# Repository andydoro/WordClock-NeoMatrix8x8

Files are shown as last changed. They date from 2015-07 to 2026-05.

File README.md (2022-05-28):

 WORD CLOCK - NeoMatrix 8x8 Desktop Edition
================
 by [Andy Doro](https://andydoro.com/) & [Dano Wall](https://github.com/danowall)
 
https://andydoro.com/wordclockdesktop/

[Adafruit Learn Guide](https://learn.adafruit.com/neomatrix-8x8-word-clock/)

A word clock which uses NeoPixel RGB LEDs for a color shifting effect.

Hardware
-------
 
 - [Trinket Pro 5V](https://www.adafruit.com/product/2000) (should work with other Arduino-compatibles with minor modifications) 
 - [DS1307 RTC breakout](https://www.adafruit.com/products/3296)
 - [NeoPixel NeoMatrix 8x8](https://www.adafruit.com/products/1487)
 - laser cut faceplate & enclosure
 
Software
-------
 
This code requires the following libraries:
 
 - [RTClib](https://github.com/adafruit/RTClib)
 - [DST_RTC](https://github.com/andydoro/DST_RTC)
 - [Adafruit_GFX](https://github.com/adafruit/Adafruit-GFX-Library)
 - [Adafruit_NeoPixel](https://github.com/adafruit/Adafruit_NeoPixel)
 - [Adafruit_NeoMatrix](https://github.com/adafruit/Adafruit_NeoMatrix)

Wiring
-------

 - Solder DS1307 breakout to Trinket Pro, A2 to GND, A3 to PWR, A4 to SDA, A5 to SCL  
   If you leave off / clip the unused SQW pin on the RTC breakout, the breakout can sit right on top of the Trinket Pro for a compact design! It'll be difficult to reach the Trinket Pro reset button, but you can activate the bootloader by plugging in the USB.
 - Solder NeoMatrix 5V to Trinket 5V, GND to GND, DIN to Trinket Pro pin 8.

grid pattern
-------

 ```
 A T W E N T Y D
 Q U A R T E R Y
 F I V E H A L F
 D P A S T O R O
 F I V E I G H T
 S I X T H R E E
 T W E L E V E N
 F O U R N I N E
 ```
 
Acknowledgements:
  - Thanks [Dano](https://github.com/danowall) for faceplate / 3D models & project inspiration!

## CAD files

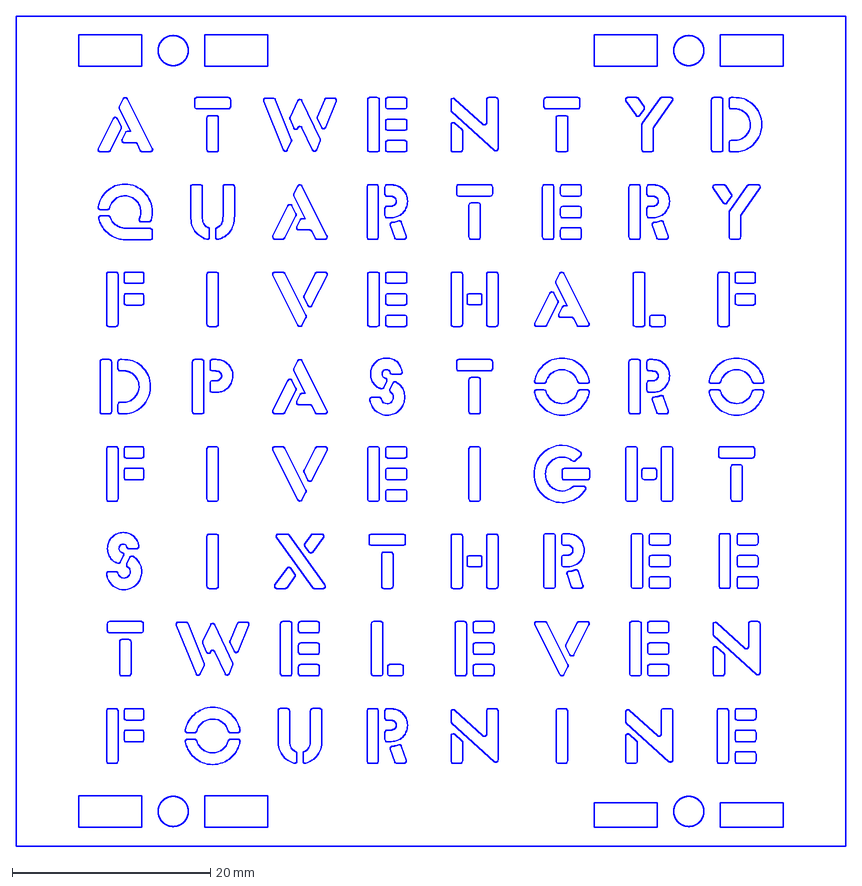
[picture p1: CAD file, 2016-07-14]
laser_cut_enclosure/wordclock_faceplate_ponoko.dxf
83.8 x 83.8 mm

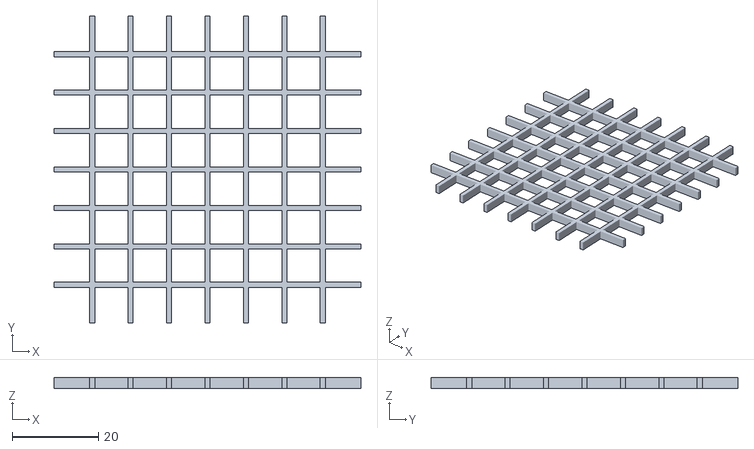
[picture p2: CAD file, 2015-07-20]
pixel_guard_3DPrint.stl
71.1 x 71.1 x 2.50

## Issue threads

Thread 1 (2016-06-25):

Invalid SVG file?

ckng2000, 2016-06-25:
Hi. I send the svg file to ponoko.com for their laser cutting service but the file turn out invalid. It is my first time trying out laser cutting may i know what could be the issue?

This is the reply from their website:

Your SVG's are coming up as 'invalid' and can not be opened. Which hints at an issue with saving/exporting settings.

What software are you using to create these SVG's? Remember when laser cutting, we can only accept correctly formatted SVG, EPS and DXF files.

Closed 2019-04-18.

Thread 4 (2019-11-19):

Unsure of correct dimensions for cutting

fishe160, 2019-11-19:
Hi,
I'm new to laser cutting, trying to use the files you provided.
When I upload them to Ponoko, only the dimensions on the clear part of the enclosure passes the laugh test. The files for the letters and the pixel guard open as 1.2mm or 296.3mm square, which must be incorrect given the size of the neopixel matrix.
Is there something I have done wrong to corrupt this measurement? I am not familiar with .svg or .dxf files.
Thanks for the help, I've already got the electronics wired and working, just need this case to put them in!
matt
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

danowall, 2019-12-04:
The faceplate should be 83.82mm (or 3.3in) on a side.
Some new AI and DXF versions of the files attached, hopefully these work better :)
[Wordclock 2D files.zip](https://github.com/andydoro/WordClock-NeoMatrix8x8/files/3923890/Wordclock.2D.files.zip)

fishe160, 2019-12-05:
Thank you for the new files!
I meant to come back and update this sooner: the issue was Ponokos website. I got them to confirm via email that it was not correctly importing .svg files. It also tried to charge me $400 for them lol.
I finished putting it together tonight, very cool! Thanks for the directions, and the code, I learned a lot from dissecting it.
Also your other projects on your website are pretty cool too.
Thanks!
matt

Closed 2019-12-05.

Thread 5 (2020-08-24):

Initial time of clock hard-coded when uploading?

buffetboy2001, 2020-08-24:
Thanks for this great project and the write-up in Make magazine. My son & I decided it would make a great first Arduino project and are now up and running with very few hitches. Online tutorial on adafuit is good.

One thing did surprise me that I want to confirm and document here (or else let you correct my understanding). We've noticed that the clock has the correct time when we upload the software (via Arduino IDE v1.8.13), but that if we then unplug the clock and let it sit off-power for a bit, then plug it in again -- it thinks the time of day is the same as when we uploaded the software. This leads me to believe that the initial time of day is being hardcoded at the time of upload. And that this setup() call below is pulling that hardcoded time as it starts watching increments from the RTC. Am I getting this correct? Or is this behavior unexpected from your perspective?

https://github.com/andydoro/WordClock-NeoMatrix8x8/blob/8de888211be5265f7b29bf51d57be477884a8d07/WordClock_NeoMatrix8x8/WordClock_NeoMatrix8x8.ino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

Running the recommended hardware and:
RTClib v_latest
DST_RTC v1.0.0 (not v1.1.1 due to bug I reported)
Adafruit_GFX v_latest
Adafruit_BusIO v_latest
Adafruit_NeoPixel v_latest
Adafruit_NeoMatrix v_latest

andydoro, 2021-02-02:
That should not happen unless the RTC is not working properly. If the RTC is detected as "not running" in the setup loop, the RTC is programmed with the date and time from the last upload. I would check to make sure the RTC is running correctly with a working battery.

Closed 2021-02-02.

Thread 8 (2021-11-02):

Word Clock displays "A Quarter To Twelve" all the time

Simboi08, 2021-11-02:
The RTC and the NeoMatrix are soldered correctly and I didn't make any changes to the code but it always displays "A Quarter To Twelve". Do you have any idea why this is happening? Thanks in advance.

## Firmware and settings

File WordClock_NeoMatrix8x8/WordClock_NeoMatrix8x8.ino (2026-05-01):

/*
   WORD CLOCK - 8x8 NeoPixel Desktop Edition
   by Andy Doro

   A word clock using NeoPixel RGB LEDs for a color shift effect.

   Hardware:
   - Trinket Pro 5V (should work with other Arduino-compatibles with minor modifications)
   - DS1307 RTC breakout
   - NeoPixel NeoMatrix 8x8


   Software:

   This code requires the following libraries:

   - RTClib https://github.com/adafruit/RTClib
   - DST_RTC https://github.com/andydoro/DST_RTC
   - Adafruit_GFX https://github.com/adafruit/Adafruit-GFX-Library
   - Adafruit_NeoPixel https://github.com/adafruit/Adafruit_NeoPixel
   - Adafruit_NeoMatrix https://github.com/adafruit/Adafruit_NeoMatrix


   Wiring:
   - Solder DS1307 breakout to Trinket Pro, A2 to GND, A3 to PWR, A4 to SDA, A5 to SCL
   If you leave off / clip the unused SQW pin on the RTC breakout, the breakout can sit right on top of the Trinket Pro
   for a compact design! It'll be difficult to reach the Trinket Pro reset button, but you can activate the bootloader by
   plugging in the USB.
   - Solder NeoMatrix 5V to Trinket 5V, GND to GND, DIN to Trinket Pro pin 8.


   grid pattern

    A T W E N T Y D
    Q U A R T E R Y
    F I V E H A L F
    D P A S T O R O
    F I V E I G H T
    S I X T H R E E
    T W E L E V E N
    F O U R N I N E


    Acknowledgements:
    - Thanks Dano for faceplate / 3D models & project inspiration!

*/

// include the library code:
#include <Wire.h>
#include <RTClib.h>
#include <DST_RTC.h>
#include <Adafruit_GFX.h>
#include <Adafruit_NeoMatrix.h>
#include <Adafruit_NeoPixel.h>

// define how to write each of the words

// 64-bit "mask" for each pixel in the matrix- is it on or off?
uint64_t mask;

// define masks for each word. we add them with "bitwise or" to generate a mask for the entire "phrase".
#define MFIVE    mask |= 0xF00000000000        // these are in hexadecimal
#define MTEN     mask |= 0x5800000000000000
#define AQUARTER mask |= 0x80FE000000000000
#define TWENTY   mask |= 0x7E00000000000000
#define HALF     mask |= 0xF0000000000
#define PAST     mask |= 0x7800000000
#define TO       mask |= 0xC00000000
#define ONE      mask |= 0x43
#define TWO      mask |= 0xC040
#define THREE    mask |= 0x1F0000
#define FOUR     mask |= 0xF0
#define FIVE     mask |= 0xF0000000
#define SIX      mask |= 0xE00000
#define SEVEN    mask |= 0x800F00
#define EIGHT    mask |= 0x1F000000
#define NINE     mask |= 0xF
#define TEN      mask |= 0x1010100
#define ELEVEN   mask |= 0x3F00
#define TWELVE   mask |= 0xF600
#define ANDYDORO mask |= 0x8901008700000000

// define pins
#define NEOPIN 8  // connect to DIN on NeoMatrix 8x8
#define RTCGND A2 // use this as DS1307 breakout ground 
#define RTCPWR A3 // use this as DS1307 breakout power


// brightness based on time of day- could try warmer colors at night?
#define DAYBRIGHTNESS 40
#define NIGHTBRIGHTNESS 20

// cutoff times for day / night brightness. feel free to modify.
#define MORNINGCUTOFF 7  // when does daybrightness begin?   7am
#define NIGHTCUTOFF   22 // when does nightbrightness begin? 10pm


// define delays
#define FLASHDELAY 250  // delay for startup "flashWords" sequence
#define SHIFTDELAY 100   // controls color shifting speed


RTC_DS1307 RTC; // Establish clock object
DST_RTC dst_rtc(0); // DST object 0 indicates US DST ruleset

DateTime theTime; // Holds current clock time

int j;   // an integer for the color shifting effect

// Do you live in a country or territory that observes Daylight Saving Time?
// https://en.wikipedia.org/wiki/Daylight_saving_time_by_country
// Use 1 if you observe DST, 0 if you don't. This is programmed for DST in the US / Canada. If your territory's DST operates differently,
// you'll need to modify the code in the calcTheTime() function to make this work properly.
//#define OBSERVE_DST 1


// Parameter 1 = number of pixels in strip
// Parameter 2 = Arduino pin number (most are valid)
// Parameter 3 = pixel type flags, add together as needed:
//   NEO_KHZ800  800 KHz bitstream (most NeoPixel products w/WS2812 LEDs)
//   NEO_KHZ400  400 KHz (classic 'v1' (not v2) FLORA pixels, WS2811 drivers)
//   NEO_GRB     Pixels are wired for GRB bitstream (most NeoPixel products)
//   NEO_RGB     Pixels are wired for RGB bitstream (v1 FLORA pixels, not v2)
//Adafruit_NeoPixel matrix = Adafruit_NeoPixel(64, NEOPIN, NEO_GRB + NEO_KHZ800);

// configure for 8x8 neopixel matrix
Adafruit_NeoMatrix matrix = Adafruit_NeoMatrix(8, 8, NEOPIN,
                            NEO_MATRIX_TOP  + NEO_MATRIX_LEFT +
                            NEO_MATRIX_ROWS + NEO_MATRIX_PROGRESSIVE,
                            NEO_GRB         + NEO_KHZ800);


void setup() {
  // put your setup code here, to run once:

  //Serial for debugging
  //Serial.begin(9600);

  // set pinmodes
  pinMode(NEOPIN, OUTPUT);

  // set analog pins to power DS1307 breakout!
  pinMode(RTCGND, OUTPUT); // analog 2
  pinMode(RTCPWR, OUTPUT); // analog 3

  // set them going!
  digitalWrite(RTCGND, LOW);  // GND for RTC
  digitalWrite(RTCPWR, HIGH); // PWR for RTC

  // start clock
  Wire.begin();  // Begin I2C
  RTC.begin();   // begin clock

  if (! RTC.isrunning()) {
    Serial.println("RTC is NOT running!");
    // following line sets the RTC to the date & time this sketch was compiled
    RTC.adjust(DateTime(__DATE__, __TIME__));
    // DST? If we're in it, let's subtract an hour from the RTC time to keep our DST calculation correct. This gives us
    // Standard Time which our DST check will add an hour back to if we're in DST.
    DateTime standardTime = RTC.now();
    if (dst_rtc.checkDST(standardTime) == true) { // check whether we're in DST right now. If we are, subtract an hour.
      standardTime = standardTime.unixtime() - 3600;
    }
    RTC.adjust(standardTime);
  }


  matrix.begin();
  matrix.setBrightness(DAYBRIGHTNESS);
  matrix.fillScreen(0); // Initialize all pixels to 'off'
  matrix.show();

  // startup sequence... do colorwipe?
  // delay(500);
  // rainbowCycle(20);
  delay(500);
  flashWords(); // briefly flash each word in sequence
  delay(500);
}

void loop() {
  // put your main code here, to run repeatedly:

  // get the time
  theTime = dst_rtc.calculateTime(RTC.now()); // takes into account DST
  // add 2.5 minutes to get better estimates
  theTime = theTime.unixtime() + 150;

  adjustBrightness();
  displayTime();

  //mode_moon(); // uncomment to show moon mode instead!


}

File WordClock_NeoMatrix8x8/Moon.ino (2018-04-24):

/*
  Adapted from phil b's TIMESQUARE WATCH code.

  Only here if you feel like it!

*/

// Moon display: shows APPROXIMATE phase of moon.  This is not a medical
// device -- do not rely on this data if you are prone to lycanthropy.
// The phase shown is based on time elapsed since a known new moon, an
// approach that the Arduino can easily process but may be limited by a
// few flaws: the "known new moon" time is based on UTC, not local time,
// and may be a few hours off; the lunar period is assumed uniform and
// is rounded to whole seconds, and thus may drift over very long periods;
// unknown long-term accuracy of RTClib (e.g. DST & leap seconds ignored);
// uses 32-bit unixtime() and thus likely innacurate in years 2038+.
// This is for fun, not Real Science(tm).

// Used by various display modes for smooth fade-out before sleep
const uint8_t PROGMEM
fade[] =
{
  0,  1,  1,  2,  4,  5,  8, 10, 13, 17, 22, 27, 32, 39, 46,
  53, 62, 71, 82, 93, 105, 117, 131, 146, 161, 178, 196, 214, 234, 255
};

static const uint8_t PROGMEM
phases[] = {
  0x3B, 0x1F, 0x01, 0x00, 0x3E, 0x26, 0x03, 0x00, 0x3F, 0x2E, 0x06, 0x00, 0x42, 0x3E, 0x07,
  0x00, 0x47, 0x56, 0x07, 0x00, 0x54, 0x7A, 0x07, 0x00, 0x81, 0x88, 0x07, 0x00, 0xCC, 0x88,
  0x07, 0x00, 0xF2, 0x88, 0x07, 0x00, 0xF2, 0x84, 0x06, 0x00, 0xF0, 0x77, 0x03, 0x00, 0xED,
  0x63, 0x01, 0x00, 0xE3, 0x42, 0x01, 0x00, 0xCE, 0x27, 0x01, 0x00, 0x96, 0x1E, 0x01, 0x00,
  0x56, 0x1E, 0x01, 0x00, 0x00, 0x0B, 0x36, 0x01, 0x00, 0x0B, 0x46, 0x06, 0x00, 0x0B, 0x60,
  0x07, 0x00, 0x0B, 0x98, 0x07, 0x00, 0x0D, 0xCC, 0x07, 0x00, 0x46, 0xE8, 0x07, 0x01, 0xFC,
  0xE8, 0x07, 0x7A, 0xFF, 0xE8, 0x07, 0xFF, 0xFF, 0xE8, 0x08, 0xFF, 0xFF, 0xE1, 0x05, 0xFF,
  0xFF, 0xC5, 0x02, 0xFF, 0xFF, 0x89, 0x01, 0xFF, 0xF5, 0x47, 0x01, 0xFF, 0x82, 0x36, 0x01,
  0xEB, 0x0D, 0x36, 0x01, 0x1F, 0x0B, 0x36, 0x01, 0x00, 0x00, 0x0B, 0x1F, 0x00, 0x00, 0x0B,
  0x47, 0x00, 0x00, 0x0B, 0x6D, 0x00, 0x00, 0x1D, 0x89, 0x00, 0x00, 0x4D, 0x88, 0x00, 0x06,
  0xFF, 0x88, 0x00, 0xC3, 0xFF, 0x88, 0x64, 0xFF, 0xFF, 0x88, 0xFF, 0xFF, 0xFF, 0x88, 0xFF,
  0xFF, 0xFF, 0x72, 0xFF, 0xFF, 0xFF, 0x4B, 0xFF, 0xFF, 0xF5, 0x22, 0xFF, 0xFF, 0x78, 0x1F,
  0xFF, 0xB8, 0x0B, 0x1F, 0xFF, 0x04, 0x0B, 0x1F, 0x26, 0x00, 0x0B, 0x1F, 0x00, 0x00, 0x00,
  0x3B, 0x00, 0x00, 0x00, 0x73, 0x00, 0x00, 0x00, 0xA4, 0x00, 0x00, 0x01, 0xF5, 0x00, 0x00,
  0x21, 0xF5, 0x00, 0x00, 0xFF, 0xF7, 0x00, 0xA0, 0xFF, 0xF5, 0x5C, 0xFF, 0xFF, 0xF5, 0xFF,
  0xFF, 0xFF, 0xF5, 0xFF, 0xFF, 0xFF, 0xDC, 0xFF, 0xFF, 0xFF, 0xA2, 0xFF, 0xFF, 0xFF, 0x59,
  0xFF, 0xFF, 0x7A, 0x3B, 0xFF, 0xF5, 0x00, 0x3C, 0xFF, 0x0C, 0x00, 0x3C, 0x2A, 0x00, 0x00,
  0x3C, 0x00, 0x00, 0x00, 0x3B, 0x00, 0x00, 0x00, 0x73, 0x00, 0x00, 0x00, 0xA4, 0x00, 0x00,
  0x01, 0xF5, 0x00, 0x00, 0x20, 0xF5, 0x00, 0x00, 0xFF, 0xF5, 0x00, 0xA0, 0xFF, 0xF5, 0x5D,
  0xFF, 0xFF, 0xF7, 0xFF, 0xFF, 0xFF, 0xF5, 0xFF, 0xFF, 0xFF, 0xDC, 0xFF, 0xFF, 0xFF, 0xA0,
  0xFF, 0xFF, 0xFF, 0x58, 0xFF, 0xFF, 0x7A, 0x3B, 0xFF, 0xF5, 0x00, 0x3C, 0xFF, 0x0C, 0x00,
  0x3C, 0x2B, 0x00, 0x00, 0x3C, 0x00, 0x00, 0x0B, 0x1F, 0x00, 0x00, 0x0B, 0x48, 0x00, 0x00,
  0x0B, 0x6D, 0x00, 0x00, 0x1D, 0x88, 0x00, 0x00, 0x4E, 0x88, 0x00, 0x06, 0xFF, 0x88, 0x00,
  0xC3, 0xFF, 0x88, 0x66, 0xFF, 0xFF, 0x88, 0xFF, 0xFF, 0xFF, 0x89, 0xFF, 0xFF, 0xFF, 0x73,
  0xFF, 0xFF, 0xFF, 0x4B, 0xFF, 0xFF, 0xF5, 0x22, 0xFF, 0xFF, 0x77, 0x1F, 0xFF, 0xB8, 0x0B,
  0x1F, 0xFF, 0x04, 0x0B, 0x1F, 0x26, 0x00, 0x0B, 0x1F, 0x00, 0x0B, 0x36, 0x01, 0x00, 0x0B,
  0x46, 0x06, 0x00, 0x0B, 0x5E, 0x07, 0x00, 0x0B, 0x9A, 0x07, 0x00, 0x0E, 0xCC, 0x07, 0x00,
  0x46, 0xE8, 0x07, 0x01, 0xFC, 0xE6, 0x07, 0x7C, 0xFF, 0xE8, 0x07, 0xFF, 0xFF, 0xE8, 0x07,
  0xFF, 0xFF, 0xE1, 0x05, 0xFF, 0xFF, 0xC7, 0x02, 0xFF, 0xFF, 0x88, 0x01, 0xFF, 0xF7, 0x48,
  0x01, 0xFF, 0x84, 0x36, 0x01, 0xEB, 0x0D, 0x36, 0x01, 0x1F, 0x0B, 0x36, 0x01, 0x3B, 0x1F,
  0x01, 0x00, 0x3F, 0x27, 0x03, 0x00, 0x3F, 0x2D, 0x06, 0x00, 0x41, 0x3E, 0x07, 0x00, 0x47,
  0x55, 0x07, 0x00, 0x52, 0x7A, 0x07, 0x00, 0x7F, 0x88, 0x07, 0x00, 0xCA, 0x88, 0x07, 0x00,
  0xF2, 0x88, 0x07, 0x00, 0xF5, 0x82, 0x06, 0x00, 0xF2, 0x77, 0x03, 0x00, 0xED, 0x63, 0x01,
  0x00, 0xE6, 0x42, 0x01, 0x00, 0xCE, 0x27, 0x01, 0x00, 0x96, 0x1F, 0x01, 0x00, 0x56, 0x1F,
  0x01, 0x00
}
,
leftHalf[]  = {
  0, 0,  0,  0,  0,  0,  0,  0, 15, 14, 13, 12, 11, 10, 9,
  8, 8,  8,  8,  8,  8,  8,  8,  7,  6,  5,  4,  3,  2, 1
}
,
rightHalf[] = {
  0, 1,  2,  3,  4,  5,  6,  7,  8,  8,  8,  8,  8,  8, 8,
  8, 9, 10, 11, 12, 13, 14, 15,  0,  0,  0,  0,  0,  0, 0
};

// Time/date of a known new moon (UNIX time) - Dec 7 1999 22:32
#define NEW_MOON 944605920
#define LP       2551443L // Lunar period in seconds

uint8_t phase = 0;

void mode_moon() {

  //DateTime theTime = RTC.now();
  phase = (uint8_t) (((theTime.unixtime() - NEW_MOON) % LP) / (24L * 3600L));

  //uint8_t  b = 255; //(uint8_t)pgm_read_byte(&fade);
  uint8_t  b = (uint8_t)pgm_read_byte(&fade);

  matrix.fillScreen(0);
  blit(phases, 64, 8, pgm_read_byte(&rightHalf[phase]) * 4 , 0, 4, 0, 4, 8, b );
  matrix.setRotation(2);
  blit(phases, 64, 8, pgm_read_byte(&leftHalf[phase])  * 4 , 0, 4, 0, 4, 8, b );
  matrix.setRotation(0);


  matrix.show();
}


void blit(const uint8_t *img, int iw, int ih, int sx, int sy, int dx, int dy,
          int w, int h, uint8_t b) {
  uint16_t b1;
  uint8_t  shift, x, y;

  shift = 16;


  if ((dx >= 8) || ((dx + w - 1) < 0)) return; // Quick X-only clipping

  b1 = (uint16_t)b + 1; // +1 so shift (rather than divide) can be used

  for (y = 0; y < h; y++) {
    for (x = 0; x < w; x++) {
      byte clr = ((uint8_t)pgm_read_byte(&img[(sy + y) * iw + sx + x]) * b1);
      if (clr > 0 && clr < 70) {
        clr = clr * 40;  // boost dim pixels
      }
      matrix.drawPixel(dx + x, dy + y,
                       matrix.Color(0, 0, clr)); // draw in blue, pale white pixels look green and funky...

    }
  }
}

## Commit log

2015-06-05 Arduino doesn't like hyphens
    [Moon.ino, WordClock_NeoMatrix8x8.ino, colorFunctions.ino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]
2015-07-07 fixed color shifting delay
    fixed color shifting delay
    [WordClock_NeoMatrix8x8.ino, colorFunctions.ino, displayTime.ino]
2015-07-07 added vector files
    added vector enclosure files.
2015-07-20 pixel guard
    added pixel guard stl
    [pixel_guard.stl]
2015-07-21 updated files
    added vector file for pixel guard, renamed stl file
    [pixel_guard_3DPrint.stl]
2015-07-24 updated stl
    updated pixel guard file to match svg
2015-07-24 moved files into enclosure folder
    moved files into enclosure folder
2015-09-29 added switch for DST
    switch for DST, fixed variables
    [WordClock_NeoMatrix8x8.ino, calcTheTime.ino]
2016-01-12 user-friendlier time setting
    broke out function to check for DST to be more user friendly when
    setting the time.
    [WordClock_NeoMatrix8x8.ino]
2016-07-14 vector file compatible with Ponoko
    Ponoko-compatible file
    [wordclock_faceplate_ponoko.dxf]
